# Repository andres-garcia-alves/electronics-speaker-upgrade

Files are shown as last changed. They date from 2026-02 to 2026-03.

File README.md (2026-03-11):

# Speaker Upgrade

Speaker modernization (50 watts, 6 ohm) to function as a semi-portable, independent device, separate from the original audio system.

The following features are added:
- Bluetooth audio reception.
- AUX input with a 3.5mm jack for wired connection.
- Slider potentiometer for volume control.
- DC connector for 12V power supply.
- On/off switch button.

&nbsp;

### Notes:

- Power input: 12 VDC
- 2 PCBs are included:
  - Main PCB: for power, BT and audio amplifier features.
  - Auxiliar PCB (for UX): volume slider, LED and AUX audio jack.

&nbsp;

### List of Materials

- 1 x Speaker 10+ watts, 6 ohms
- 1 x Audio Amplifier AN7522N 5W+5W + Heat Sink
- 1 x BT receiver WIN-668 module
- 1 x Lineal Regulator TP7805 + Heat Sink
- 1 x Capacitor 2200uf (electrolitic)
- 1 x Capacitor 1000uf (electrolitic)
- 1 x Capacitor 470uf (electrolitic)
- 1 x Capacitor 10uf (electrolitic)
- 4 x Capacitor 100nf (ceramic)
- 1 x Potentiometer 50K (slider)
- 1 x Resistor 1M ohms
- 1 x Resistor 330K ohms
- 1 x Resistor 47K ohms
- 2 x Resistor 22K ohms
- 2 x Resistor 10K ohms
- 4 x Resistor 3.3K ohms
- 1 x Resistor 680 ohms
- 1 x LED 5mm
- 1 x Audio jack 3.5mm
- 1 x Switch button (audio source)
- 1 x Rocker button (power on/off)
- 1 x DC Jack (power)
- 1 x JST 2-pins connector (or similar)
- 1 x JST 5-pins connector (or similar)
- 1 x JST 6-pins connector (or similar)
- Wires

&nbsp;

### Screenshots

| Breadboard | Assembly |
|---|---|
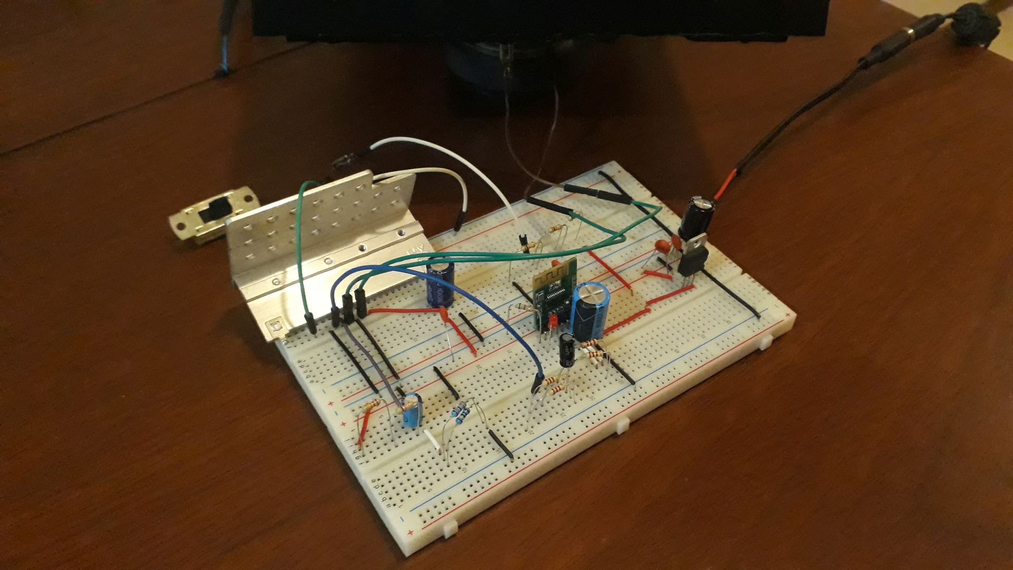
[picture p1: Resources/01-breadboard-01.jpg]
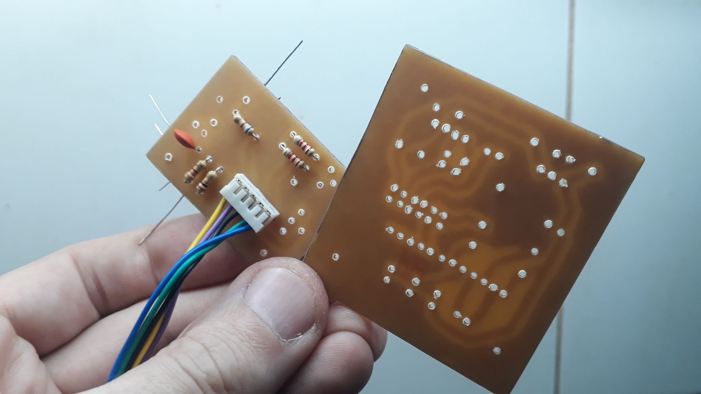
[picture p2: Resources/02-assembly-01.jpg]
|  |  |

| Assembly | Assembly |
|---|---|
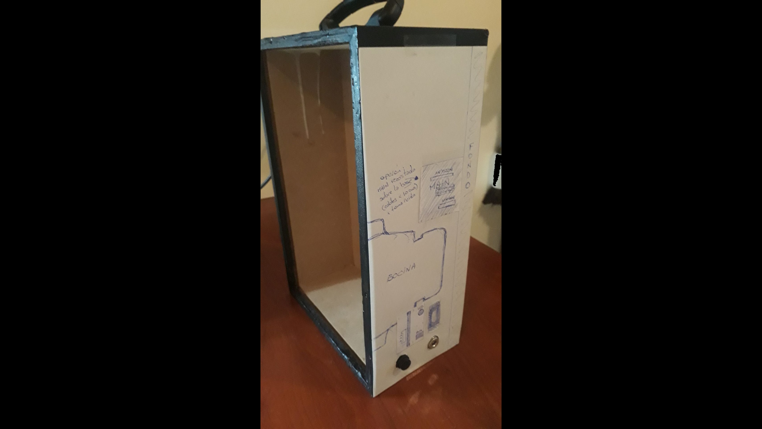
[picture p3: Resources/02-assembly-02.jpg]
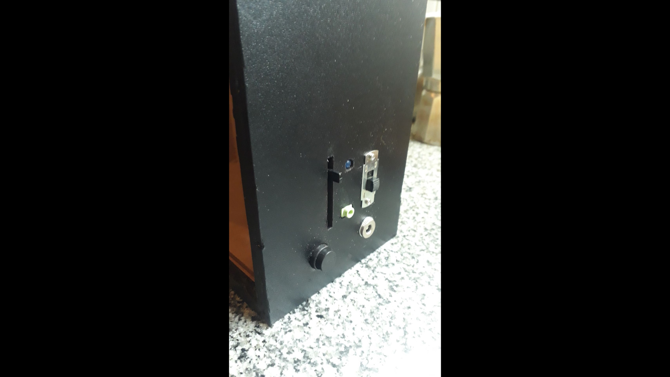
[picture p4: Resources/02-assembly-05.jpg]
|  |  |

| Schematics Diagram | PCB Diagram |
|---|---|
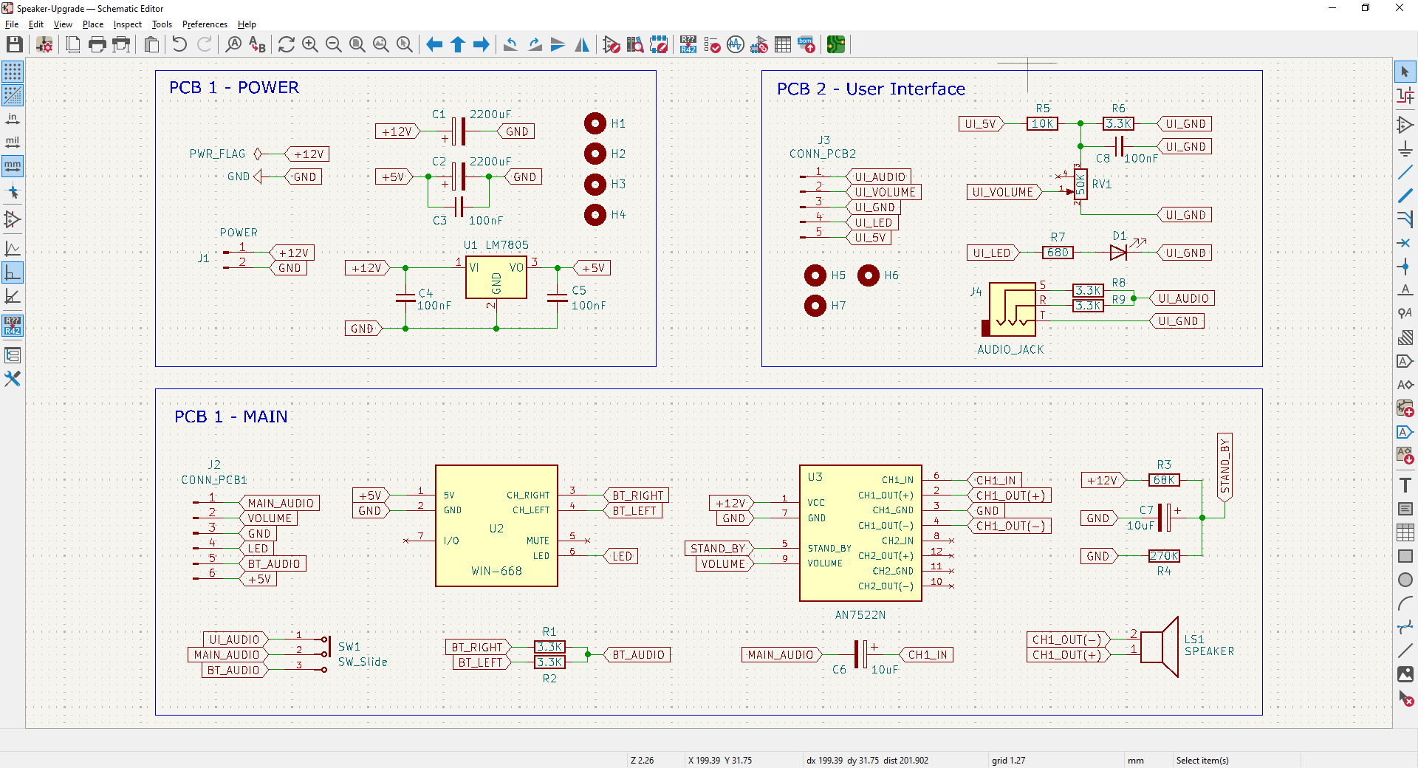
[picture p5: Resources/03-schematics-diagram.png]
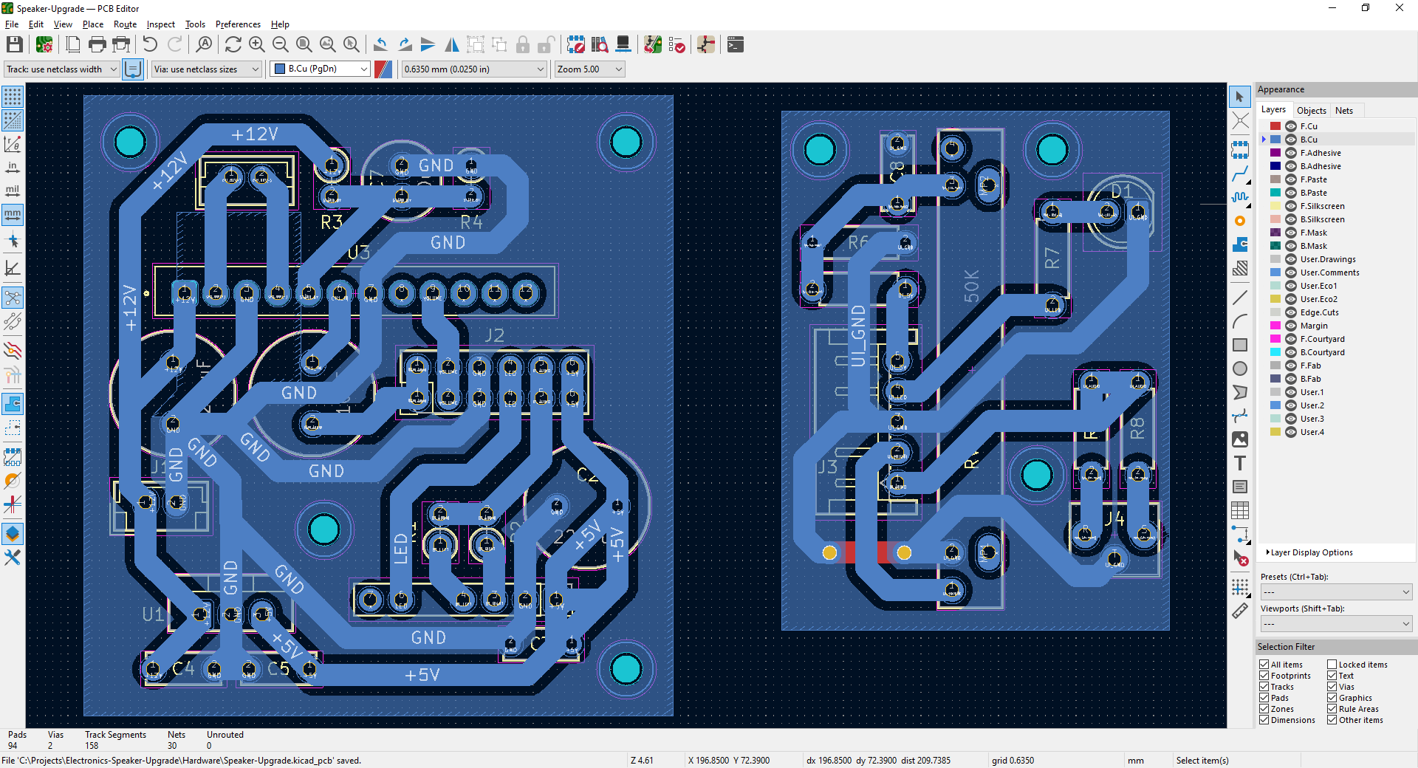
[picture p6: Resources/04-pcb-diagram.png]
|  |  |

| PCB Render 3D | PCB Render 3D |
|---|---|
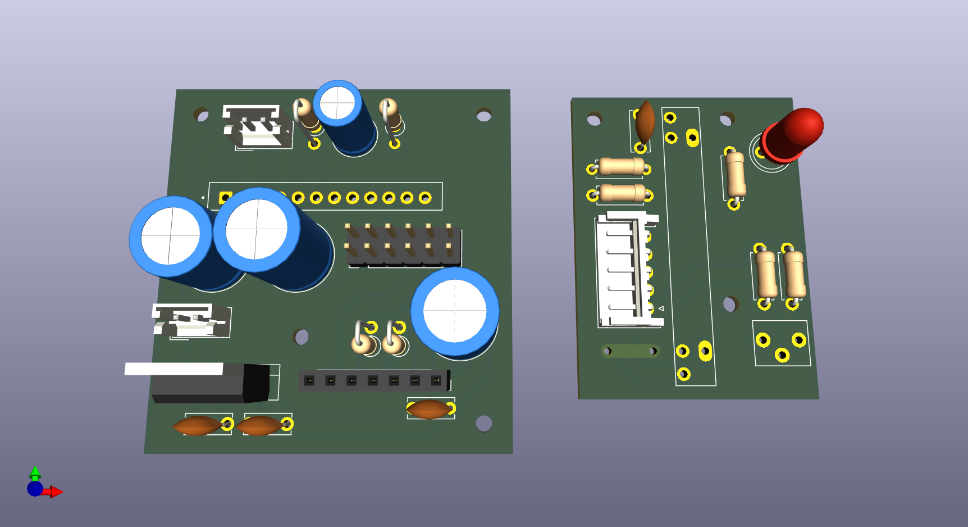
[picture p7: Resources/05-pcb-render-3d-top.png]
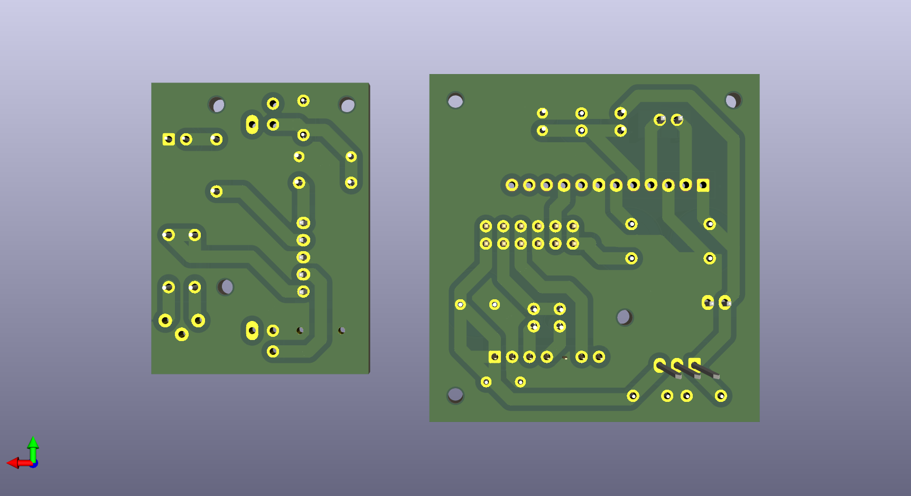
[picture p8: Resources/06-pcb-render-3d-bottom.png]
|  |  |

| Project Final | Project Final |
|---|---|
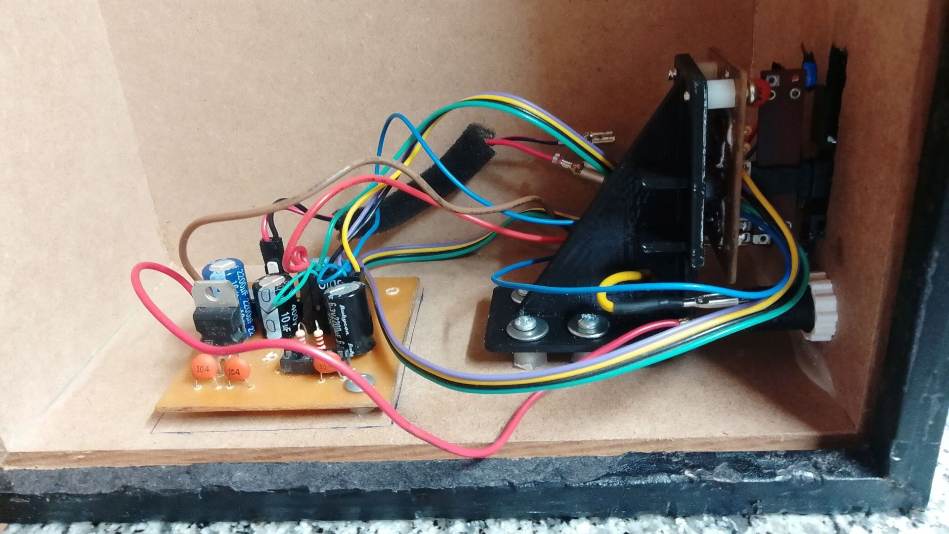
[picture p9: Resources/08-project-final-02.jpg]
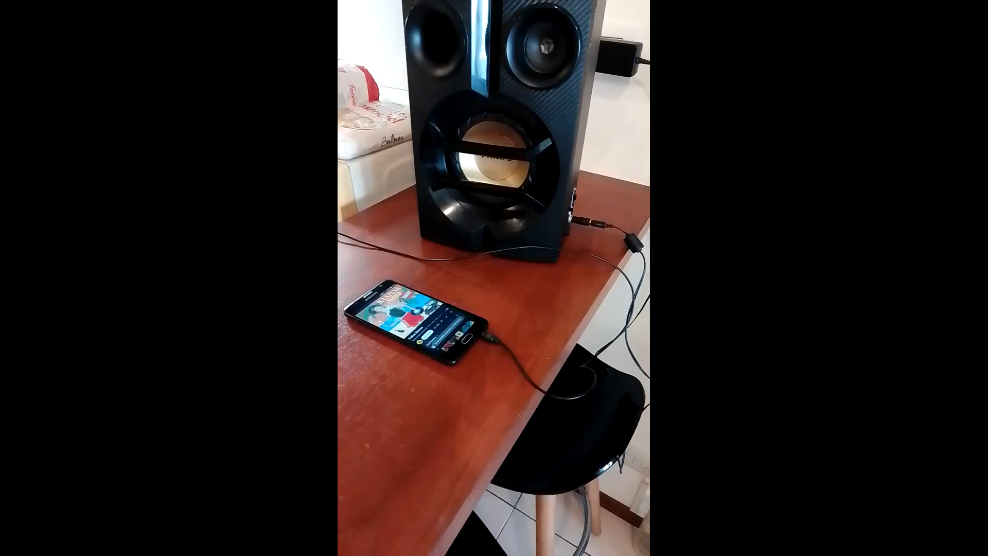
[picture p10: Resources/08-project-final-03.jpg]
|  |  |

See 'Resources' folder for more pictures & videos of the project.

&nbsp;

### Version History

v1.0 (2026.02.15) - Adding base schematics and PCB.  
v1.1 (2026.02.16) - Improvements on schematics and PCB.  
v1.2 (2026.02.17) - Minor improvements on schematics and PCB.  
v1.3 (2026.02.21) - Minor improvements on schematics and PCB.  

&nbsp;

This source code is licensed under GPL v3.0  
Please send me your feedback about this project: andres.garcia.alves@gmail.com

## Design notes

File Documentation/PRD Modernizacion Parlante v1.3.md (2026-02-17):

# PRD – Modernización de Parlante Philips con Bluetooth

## 1. Objetivo del proyecto
Modernizar un parlante Philips pasivo de mediados de los 2000 para que funcione de manera autónoma respecto a su equipo de audio original, incorporando recepción de audio por Bluetooth, amplificación interna y alimentación desde la red eléctrica mediante una fuente externa.

El proyecto prioriza:
- Reutilización de componentes existentes
- Aprendizaje práctico de electrónica de audio
- Diseño modular y entendible (no solución "todo en uno")

---

## 2. Alcance

### Incluido
- Conversión de parlante pasivo a parlante activo
- Recepción de audio Bluetooth
- Recepción de audio (entrada AUX) vía ficha mini-plug
- Amplificación mono interna
- Alimentación mediante fuente externa DC
- Control de encendido y volumen
- Prototipo funcional probado en protoboard

### Excluido
- Alimentación por baterías
- Portabilidad total
- Potencia de salida nivel "fiesta"

---

## 3. Requisitos funcionales

### RF-01 – Entrada de audio
- El sistema debe recibir audio de forma inalámbrica vía Bluetooth.
- El audio recibido debe ser compatible con fuentes estéreo estándar (teléfono, PC, etc.).
- El sistema debe recibir audio de forma cableada a través de entrada AUX con un jack 3.5 mm.

### RF-02 – Conversión estéreo a mono
- El audio estéreo debe mezclarse correctamente a mono.
- No se permite la unión directa de canales L y R.
- Se utilizará una red resistiva para la mezcla (ej. 2 resistencias).

### RF-03 – Amplificación
- El sistema debe amplificar la señal de audio mono y excitar un parlante de 6 Ω.
- La amplificación se realizará mediante un IC clase AB reutilizado.

### RF-04 – Control de volumen
- El usuario debe poder regular el volumen mediante un potenciómetro externo.
- Se utilizará el control de volumen interno del IC amplificador.

### RF-05 – Alimentación
- El sistema debe alimentarse desde una fuente externa DC.
- Debe incluir interruptor físico de encendido/apagado.

---

## 4. Componentes principales

### 4.1 Parlante
- Marca: Philips
- Tipo: Pasivo
- Potencia nominal: 50 W (no RMS)
- Impedancia: 6 Ω
- Se reutiliza la caja original
- Tamaño: 20.4 x 30.8 x 11.5 cm

### 4.2 Amplificador
- Modelo: AN7522N (Panasonic / Matsushita)
- Tipo: Amplificador de audio clase AB
- Configuración: BTL interno por canal
- Uso previsto: 1 canal en modo mono
- Potencia estimada: ~5 W sobre 6–8 Ω

### 4.3 Módulo Bluetooth
- Modelo: WIN-668
- Alimentación: 5 V
- Función: Fuente de señal de audio

### 4.4 Regulación de tensión
- Tipo: Regulardor Lineal
- Modelo: TP7805
- Función: Conversión de 12 V → 5 V para el módulo Bluetooth
- Justificación: evitar introducir ruido de switching

---

## 5. Arquitectura del sistema

### Diagrama conceptual

- Fuente externa DC (≈12 V)
  - Interruptor ON/OFF
  - Línea directa al amplificador
  - Línea regulada (TP7805) hacia módulo Bluetooth

- Flujo de señal de audio:
  - Bluetooth (L/R) o ficha mini-plug (L/R)
  - Mezcla estéreo → mono
  - Potenciómetro para control de volumen (pin 9 del IC)
  - Entrada de audio del AN7522N (pin 6 del IC)
  - Salida BTL hacia el parlante (pines 2 y 4 del IC)

---

## 6. Requisitos eléctricos

### Alimentación
- Tensión principal: 12 V DC nominal
- Corriente estimada total: < 2 A

### Regulación
- Salida regulada: 5 V DC
- Corriente esperada módulo BT: < 100 mA

### Filtrado
- Capacitor electrolítico de bulk en línea de 12 V
- Capacitor electrolítico de bulk en VCC del módulo BT
- Capacitores de desacople (cerámicos) cerca de cada IC

---

## 7. Requisitos térmicos

- El AN7522N debe contar con disipador térmico.
- El diseño debe contemplar ventilación pasiva dentro de la caja.
- Uso típico: 8 hs de uso contínuo.

---

## 8. Requisitos mecánicos

- Todos los componentes deben alojarse dentro de la caja original del parlante.

- Elementos ya incorporados:
  - Jack DC lateral
  - Interruptor ON/OFF
  - Manija superior

- Se debe preservar la integridad estructural y estética del gabinete.

- Largo de los cables de potencia (amplificador → bocina) no debería superar los 8-10 cms
para minimizar ruido en el audio (cables más largos pueden hacer las veces de antena).

---

## 9. Requisitos de calidad de audio

- Distorsión baja a volumen doméstico.
- Ruido de fondo mínimo.
- Sin zumbidos audibles provenientes de la fuente o del módulo BT.

---

## 10. Etapas del proyecto

1. Análisis de componentes y arquitectura
2. Diseño del esquema eléctrico mínimo
3. Prototipo en protoboard del amplificador AN7522N
4. Integración del módulo Bluetooth y regulación
5. Pruebas funcionales y térmicas
6. Reducción de ruido (si lo hubiera)
7. Ajustes fino del diseño
8. Diseño del PCB (en KiCAD 9)

---

## 11. Consideraciones futuras (fuera de alcance actual)

- Agregado de control de tono

---

## 12. Lista de componentes sugeridos (etapa protoboard)

### 12.1 Etapa de potencia (AN7522N)
- IC amplificador: **AN7522N**
- Alimentación: **12 V DC**
- Capacitor bulk VCC: **2200 µF electrolítico** (entre VCC y GND)
- Capacitor cerámico desacople: **100 nF** (a agregar en etapa de reducción de ruido)
- Disipador de aluminio tipo 'T' (verificado térmicamente)

### 12.2 Stand-by / Soft-start (pin 5)
- Resistencia a VCC: **68 kΩ**
- Resistencia a GND: **330 kΩ ∥ 1 MΩ ≈ 248 kΩ** (o 330 kΩ sola como alternativa válida)
- Capacitor a GND: **10 µF electrolítico**

### 12.3 Control de volumen (según datasheet)
- Potenciómetro lineal: **50 kΩ (slider)**
- Capacitor opcional anti-ruido: **100 nF a GND desde pin VOL**
- Rango de control resultante: **0–1.25 V DC**

### 12.4 Entrada de audio Bluetooth (WIN-668)
- Regulador: TP7805 (12 V → 5 V)
- Capacitor acople audio: **10 µF electrolítico**
- Resistencia para Mix L/R: **3.3 kΩ** (opción 4.7 kΩ a evaluar)

### 12.5 Entrada AUX por cable
- Jack estéreo común
- Capacitor de acople por canal: **1–10 µF**
- Resistencia para Mix L/R: **3.3 kΩ** (opción 4.7 kΩ a evaluar)
- Nota PRD: **Por simplicidad del diseño, módulo BT y TP7805 permanecen siempre energizados**

### 12.6 Manejo de las fuentes de audio
- Conmutación de señal mediante switch SPDT

### 12.7 Pendientes de la etapa protoboard
- Reducción de ruido / fritura:
  - Agregar cerámicos de desacople
  - Filtrado de alimentación BT y amplificador
  - Evaluar impacto de resistencias serie mayores
- Validar entrada AUX
- Medir ruido con BT desconectado vs conectado

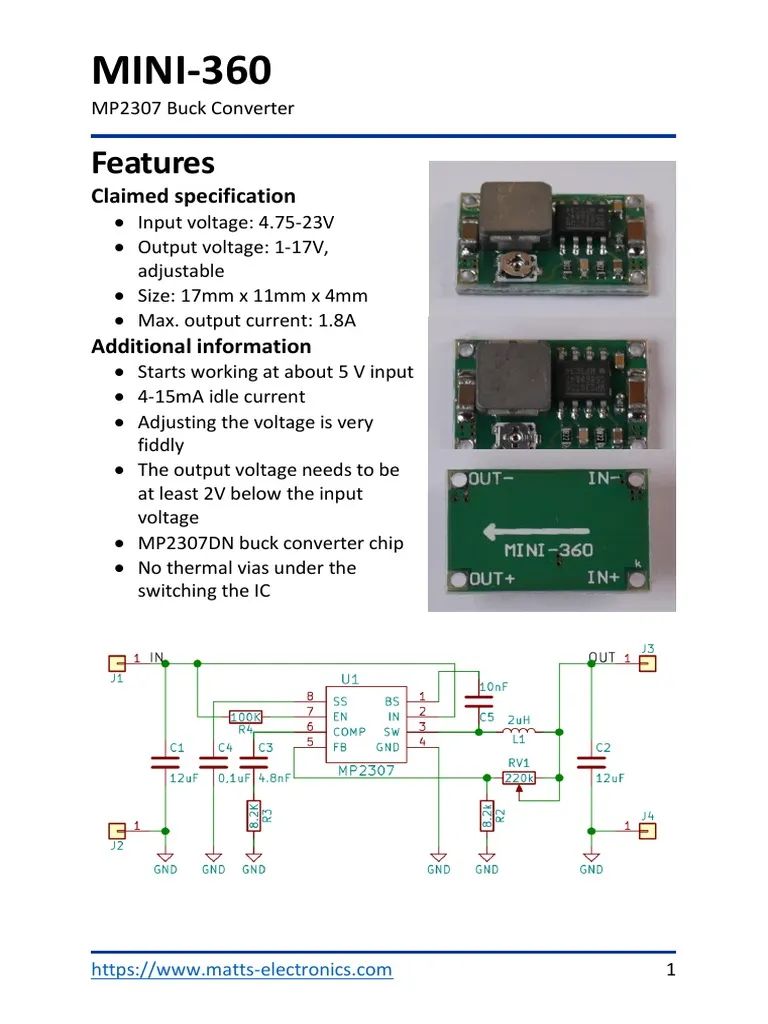
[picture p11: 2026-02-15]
Datasheets/DC-DC Buck Converter Mini-360 Specs.jpg

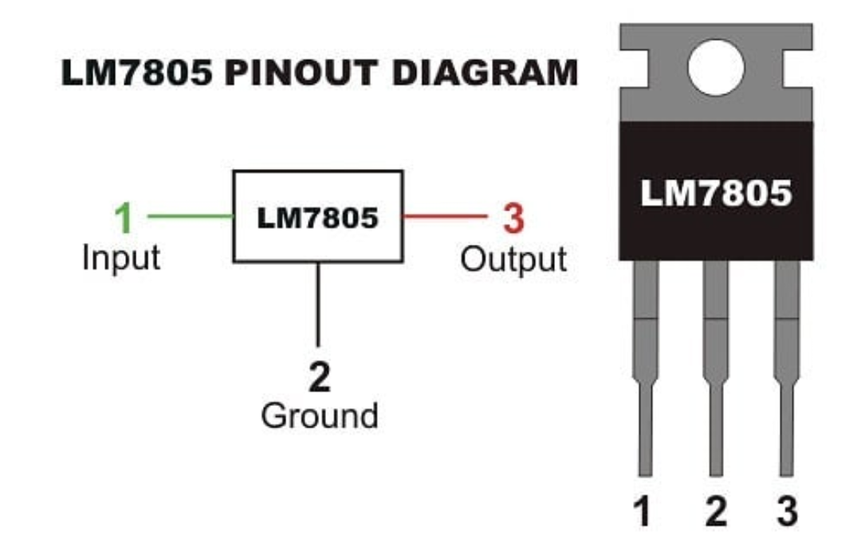
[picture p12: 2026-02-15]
Datasheets/Lineal Regulator TP7805 Pinout.png

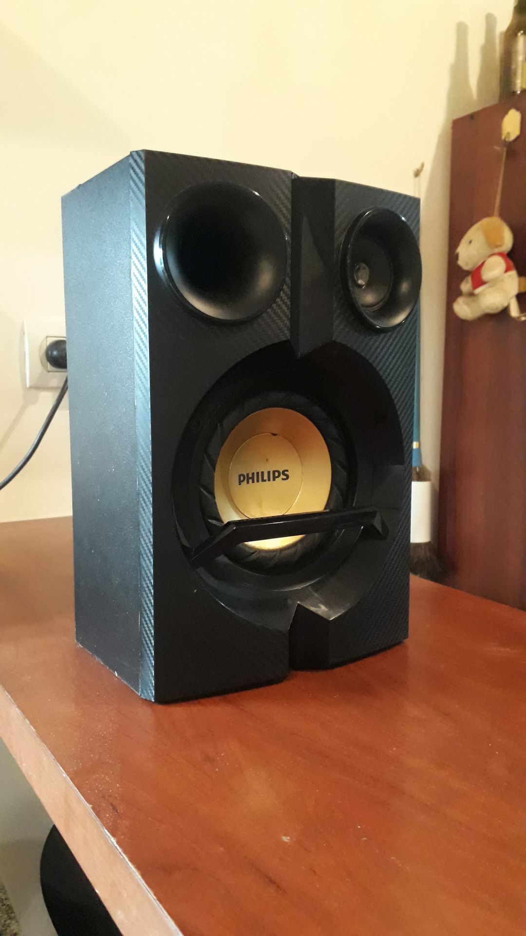
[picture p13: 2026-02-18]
Resources/00-project-start.jpg

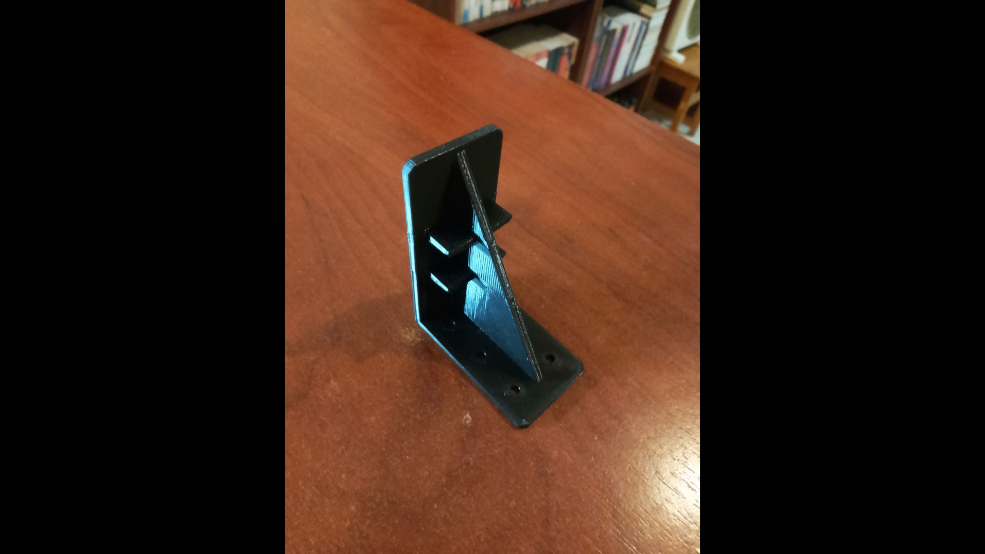
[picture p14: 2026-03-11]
Resources/07-model-3d.jpg

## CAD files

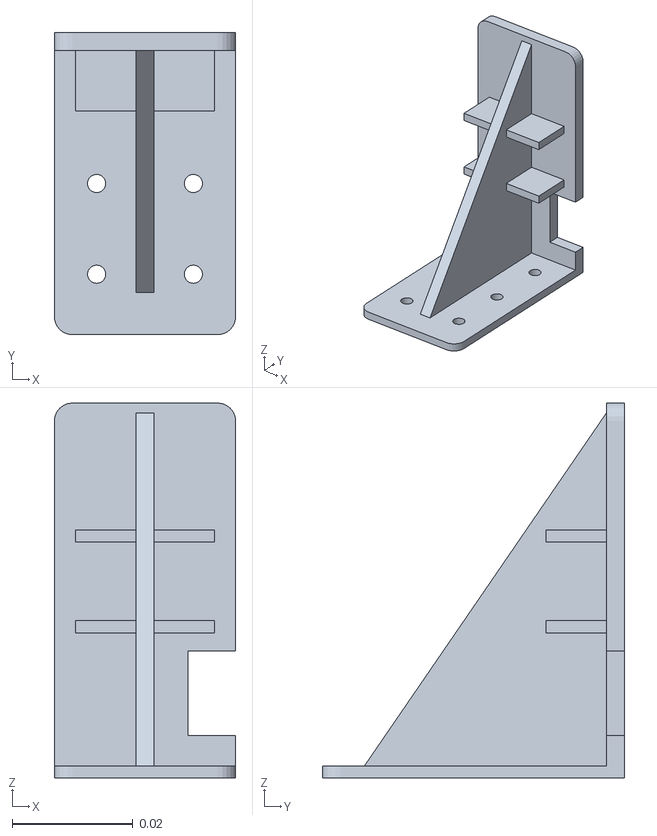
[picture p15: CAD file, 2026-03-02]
3D Models/PCB Backing 30x50x62mm (final).stl
0.03 x 0.05 x 0.062

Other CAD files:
3D Models/PCB Backing 30x50x62mm (final).blend
3D Models/PCB Backing 30x50x62mm (without holes).blend

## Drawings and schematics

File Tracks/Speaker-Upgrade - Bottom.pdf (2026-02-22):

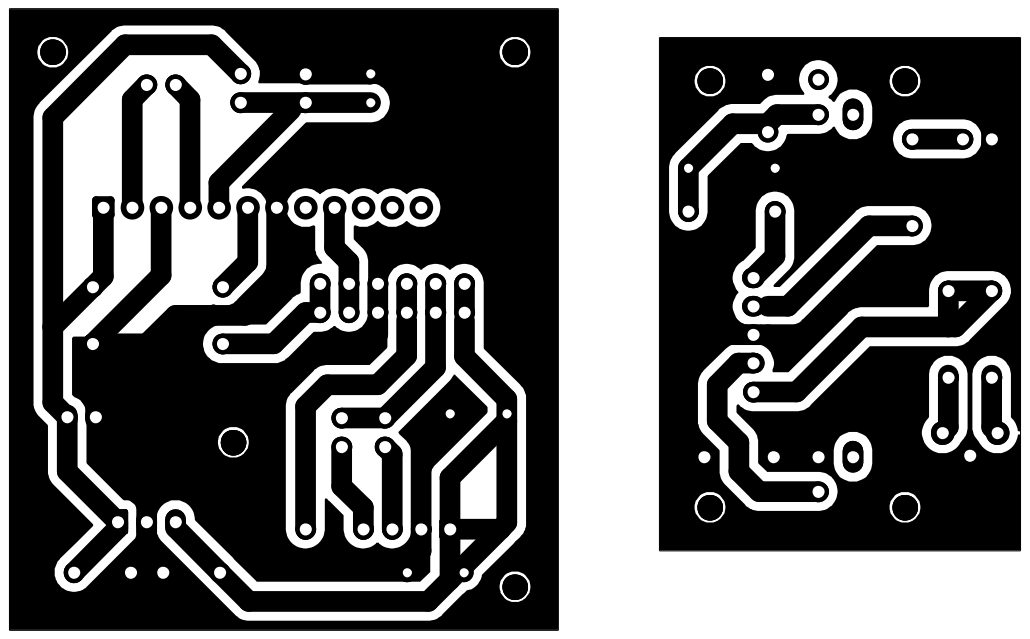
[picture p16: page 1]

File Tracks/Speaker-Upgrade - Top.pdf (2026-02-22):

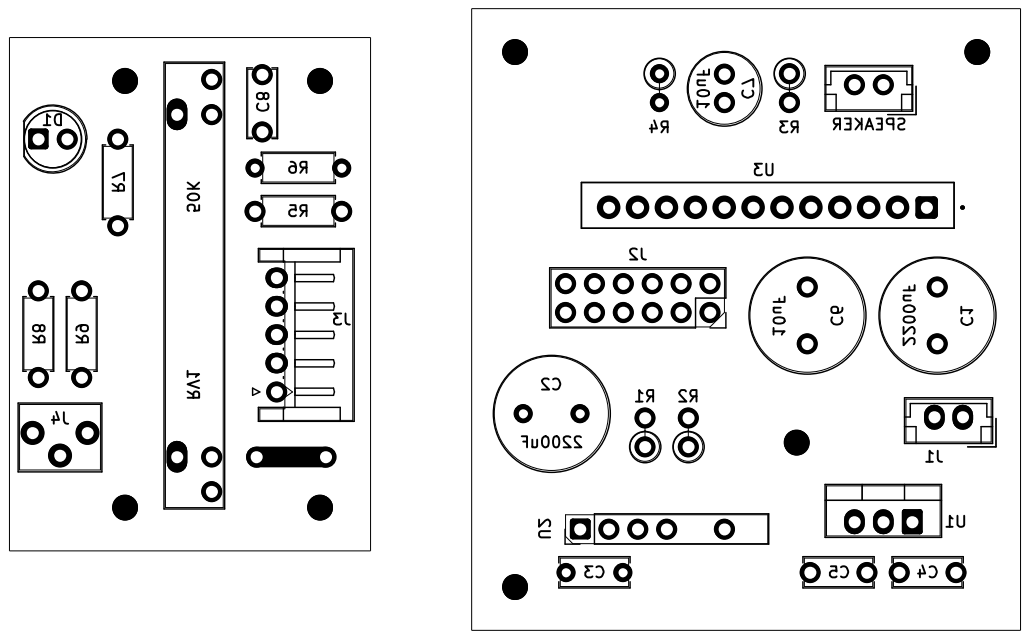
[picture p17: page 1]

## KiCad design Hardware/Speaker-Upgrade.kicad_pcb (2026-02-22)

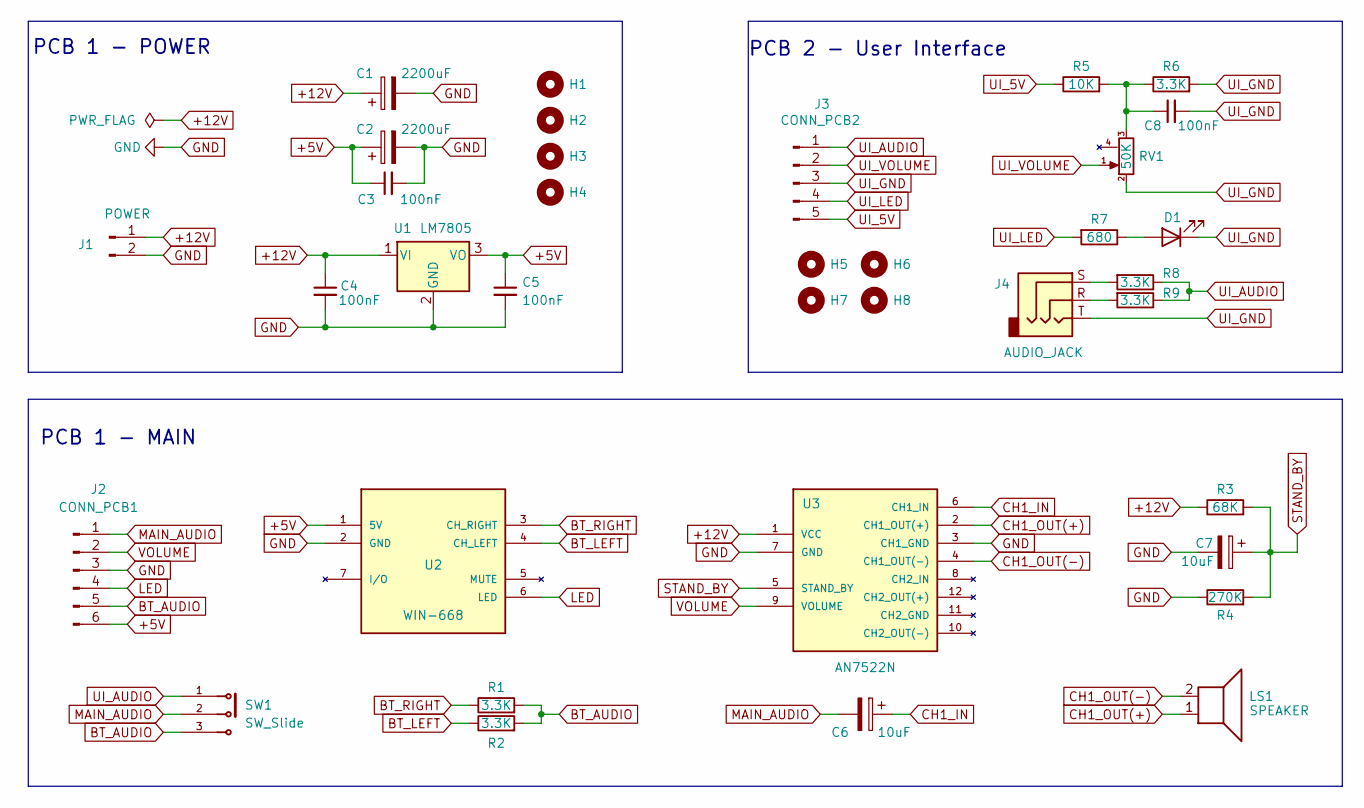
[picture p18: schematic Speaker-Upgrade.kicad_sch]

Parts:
C1: 2200uF; C_Radial_D10.0mm_H12.5mm_P5.00mm
C2: 2200uF; C_Radial_D10.0mm_H16.0mm_P5.00mm
C3, C4, C5, C8: 100nF; C_Disc_D6.0mm_W2.5mm_P5.00mm
C6: 10uF; C_Radial_D10.0mm_H16.0mm_P5.00mm
C7: 10uF; C_Radial_D6.3mm_H11.0mm_P2.50mm
D1: LED; LED_D5.0mm
H1, H2, H3, H4, H5, H6, H7, H8: MountingHole; MountingHole_2.2mm_M2
J1: POWER; JST_EH_B2B-EH-A_1x02_P2.50mm_Vertical
J2: CONN_PCB1; PinHeader_2x06_P2.54mm_Vertical
J3: CONN_PCB2; JST_EH_S5B-EH_1x05_P2.50mm_Horizontal
J4: AUDIO_JACK; Jack_3.5mm_Vertical
LS1: SPEAKER; JST_EH_B2B-EH-A_1x02_P2.50mm_Vertical
R1, R2: 3.3K; R_Axial_DIN0207_L6.3mm_D2.5mm_P2.54mm_Vertical
R3: 68K; R_Axial_DIN0207_L6.3mm_D2.5mm_P2.54mm_Vertical
R4: 270K; R_Axial_DIN0207_L6.3mm_D2.5mm_P2.54mm_Vertical
R5: 10K; R_Axial_DIN0207_L6.3mm_D2.5mm_P7.62mm_Horizontal
R6, R8, R9: 3.3K; R_Axial_DIN0207_L6.3mm_D2.5mm_P7.62mm_Horizontal
R7: 680; R_Axial_DIN0207_L6.3mm_D2.5mm_P7.62mm_Horizontal
RV1: 50K; Potentiometer_Custom_Variant_A
SW1: SW_Slide; SW_1825159-1
U1: LM7805; TO-220-3_Vertical
U2: WIN-668; PinSocket_1x07_P2.54mm_Vertical
U3: AN7522N; Audio_Amplifier_AN7522N

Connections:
+5V: C2.1, C3.1, C5.1, J2.6, U1.3 (VO), U2.1 (5V)
+12V: C1.1, C4.1, J1.1, R3.1, U1.1 (VI), U3.1 (VCC)
BT_AUDIO: J2.5, R1.2, R2.2, SW1.3
BT_LEFT: R2.1, U2.4 (CH_LEFT)
BT_RIGHT: R1.1, U2.3 (CH_RIGHT)
CH1_IN: C6.1, U3.6 (CH1_IN)
CH1_OUT(+): LS1.1, U3.2 (CH1_OUT(+))
CH1_OUT(-): LS1.2, U3.4 (CH1_OUT(-))
GND: C1.2, C2.2, C3.2, C4.2, C5.2, C7.2, J1.2, J2.3, R4.1, U1.2 (GND), U2.2 (GND), U3.3 (CH1_GND), U3.7 (GND)
LED: J2.4, U2.6 (LED)
MAIN_AUDIO: C6.2, J2.1, SW1.2
unnamed: C8.1, R5.2, R6.1, RV1.3
unnamed: D1.2 (A), R7.1
unnamed: J4.R, R9.2
unnamed: J4.S, R8.2
STAND_BY: C7.1, R3.2, R4.2, U3.5 (STAND_BY)
UI_5V: J3.5, R5.1
UI_AUDIO: J3.1, R8.1, R9.1, SW1.1
UI_GND: C8.2, D1.1 (K), J3.3, J4.T, R6.2, RV1.2
UI_LED: J3.4, R7.2
UI_VOLUME: J3.2, RV1.1
VOLUME: J2.2, U3.9 (VOLUME)

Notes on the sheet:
PCB 2 - User Interface
PCB 1 - POWER
PCB 1 - MAIN

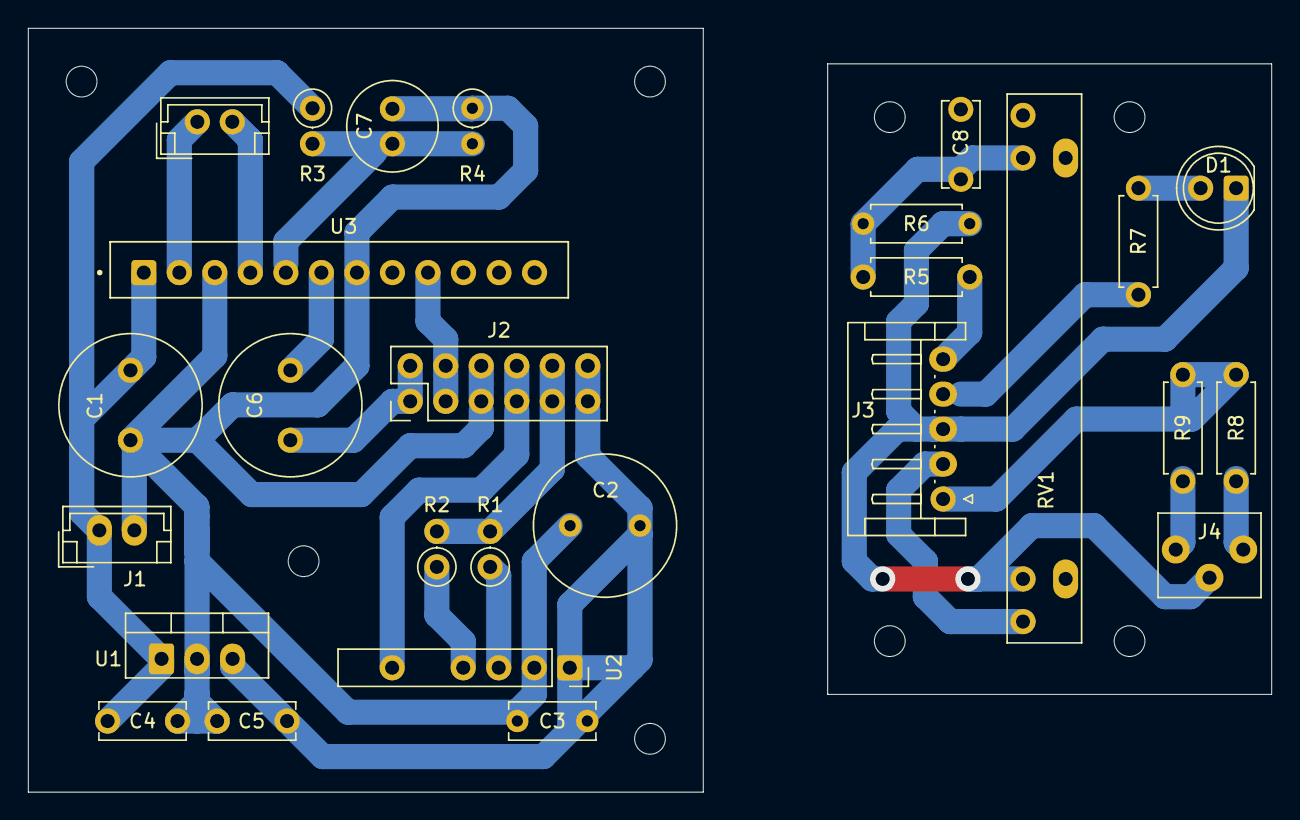
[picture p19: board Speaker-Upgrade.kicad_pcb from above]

Board: 2 copper layers, 88.9 x 54.6 mm, 35 parts (0 on the bottom side), 22 nets.

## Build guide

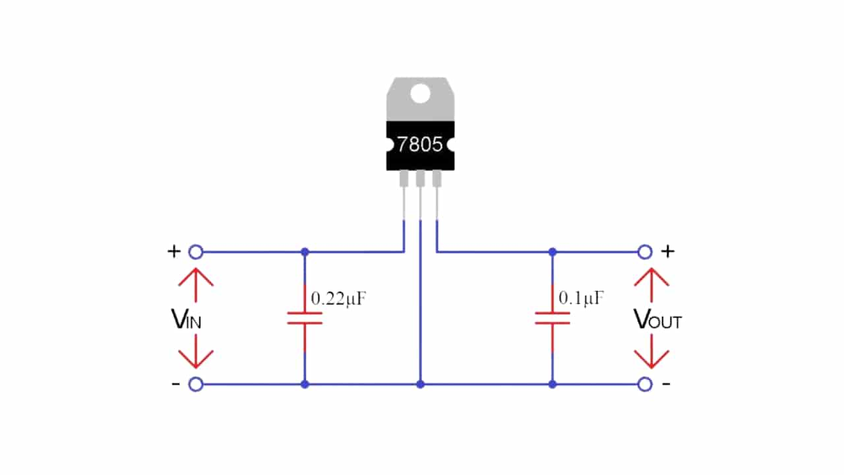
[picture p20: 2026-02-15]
Datasheets/Lineal Regulator TP7805 Wiring.jpg

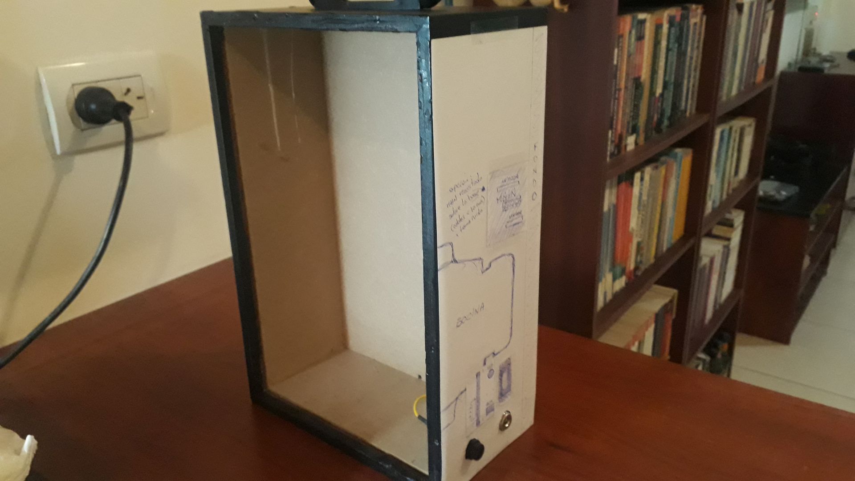
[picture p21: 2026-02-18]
Resources/02-assembly-03.jpg

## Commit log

2026-02-16 Improvements on schematics and PCB
    [Speaker-Upgrade.kicad_pcb, Speaker-Upgrade.kicad_sch]
2026-02-17 Minor improvements on schematics and PCB
    [Speaker-Upgrade.kicad_pcb, Speaker-Upgrade.kicad_sch]
2026-03-02 Adding 3D model
    [PCB Backing 30x50x62mm (final).blend, PCB Backing 30x50x62mm (final).stl, PCB Backing 30x50x62mm (without holes).blend]
